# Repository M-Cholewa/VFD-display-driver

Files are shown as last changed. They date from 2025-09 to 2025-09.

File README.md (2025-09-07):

# VFD Display Driver – HL-D336WA

This project provides both hardware (PCB) and firmware (FreeRTOS-based) for driving a **cheap HL-D336WA VFD display** (around $3 from China).  
The PCB was manufactured by **JLCPCB**, and the driver allows the display to be controlled through **SPI**.

Check out the **[Reddit r/electronics discussion here](https://www.reddit.com/r/electronics/comments/1n96cpo/my_3_vfd_vacuum_fluorescent_display_driver/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).**

---

**Display – All Segments Enabled**  
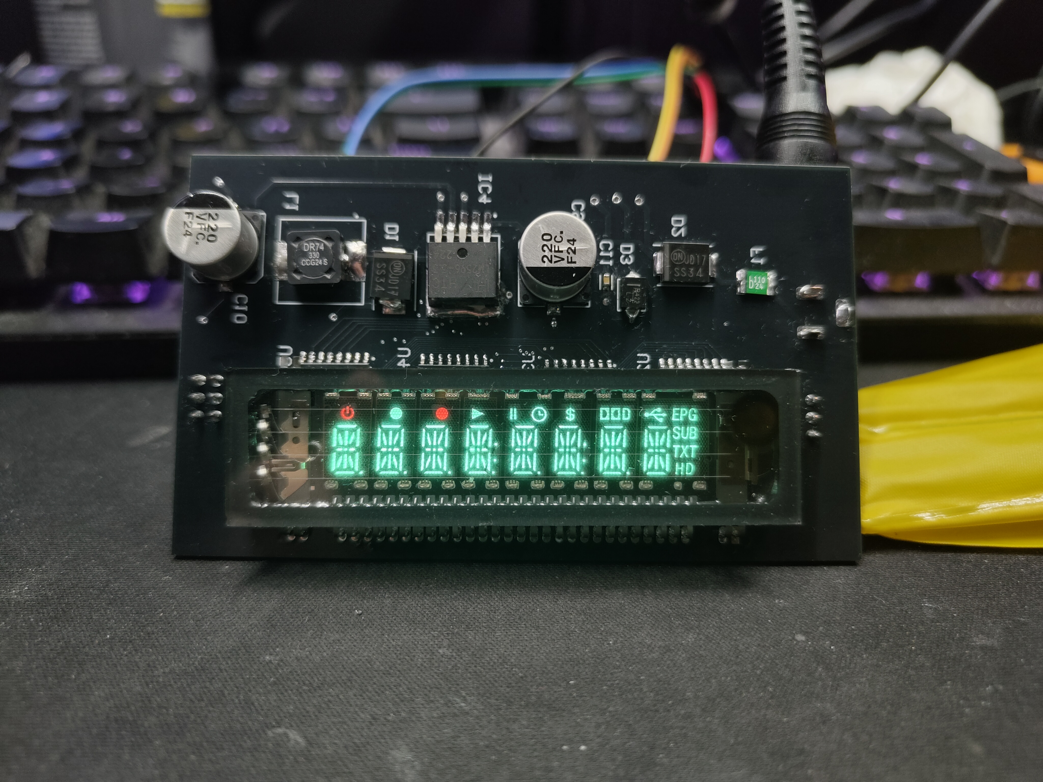
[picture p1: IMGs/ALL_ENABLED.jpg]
ALL_ENABLED


## Features

- Support for the **HL-D336WA VFD display**
- **FreeRTOS firmware** for efficient task handling
- **SPI interface** for control
- Example script for **Raspberry Pi** included ([`/RPI_SCRIPT`](./RPI_SCRIPT))
- Refresh rate: **60 Hz**
- Full control over **each segment and column**

---

## Hardware Notes

⚠️ **Important schematic note:**  
The provided schematic is **not 100% correct**.  
- Pins **COM** of the `ULN2003ADR` were incorrectly tied to **GND**.  
- To make the board work, the COM pins had to be **lifted during soldering** (left floating).  

Please keep this in mind if you want to replicate the hardware.

---

## Repository Structure

- `/FW` – FreeRTOS firmware for the controller  
- `/HW` – Hardware design files  
- `/RPI_SCRIPT` – Example Python script for Raspberry Pi to display data  
- `/IMGs` – Images, PCB renders, and schematic  

---

## Raspberry Pi Example

The controller can be driven directly via **SPI**.  
An example script is provided in [`/RPI_SCRIPT`](./RPI_SCRIPT), showing how to send data to the display.

---

## Schematic

📄 [Main schematic PDF](./IMGs/VFD_controller_stm_SCHEMATIC.pdf)

---

## Hardware Interfaces & Power

The board includes connectors for **SPI**, **SWD**, and a **DC power jack** (male, angled 90°, THT, 5.5/2.5 mm). Power is supplied from a standard **19 V laptop adapter**, which is then stepped down by an onboard converter to **3.3 V for the CPU**. The **SPI interface is galvanically isolated** using an **ADUM1401**, and the board is protected against short circuits with a **1 A PTC fuse** and **SS34 diode**.

All connectors are ESD protected.

---

## Screenshots & Diagrams

**Main Board Schematic**  
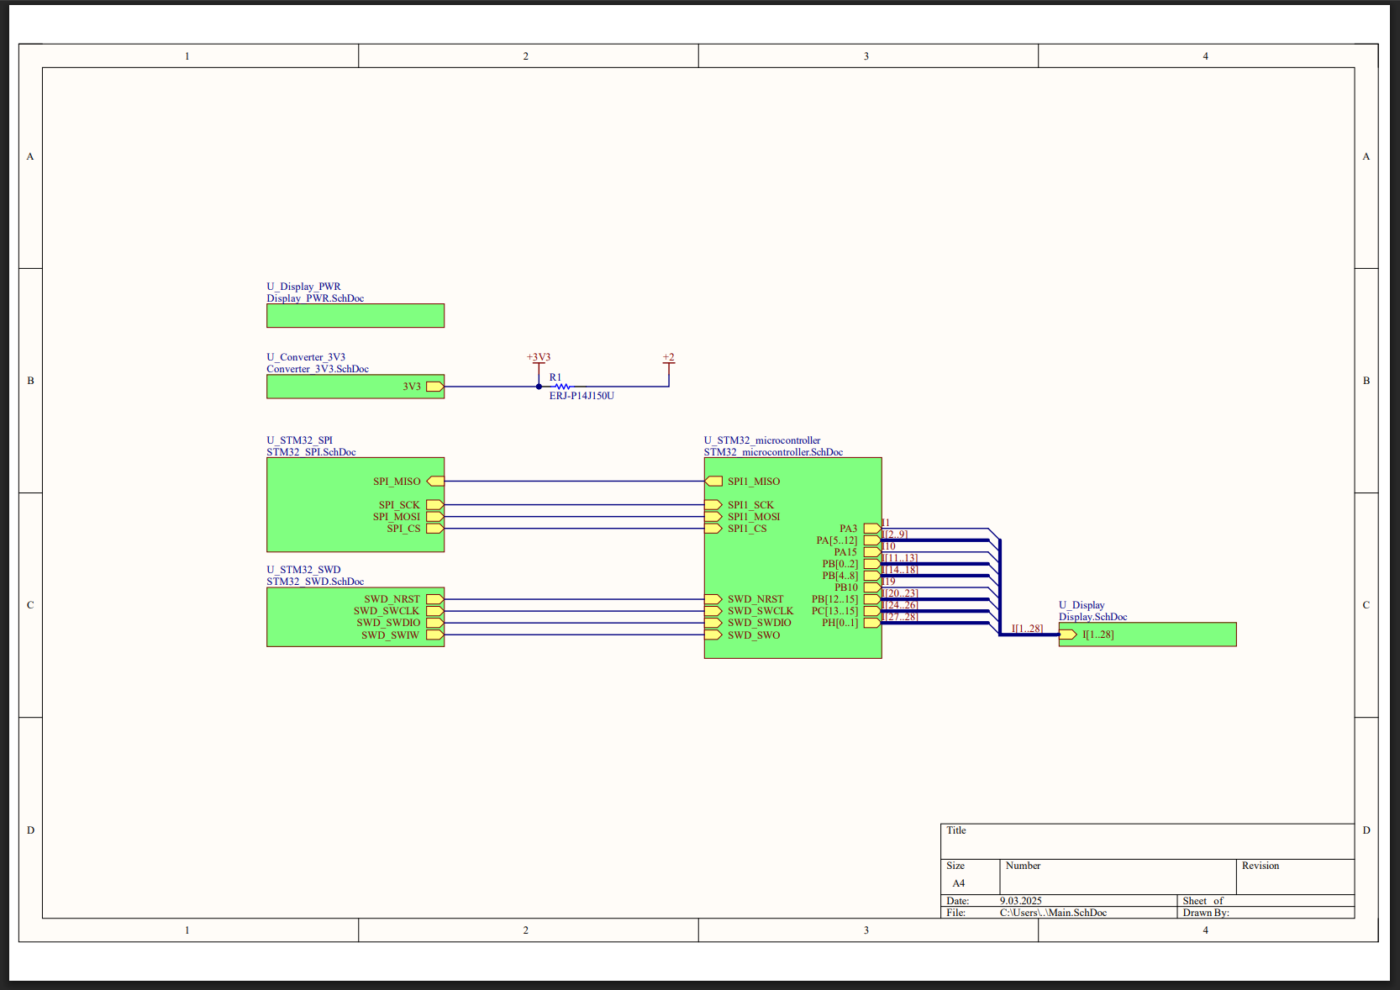
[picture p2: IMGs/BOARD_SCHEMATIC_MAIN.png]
BOARD_SCHEMATIC_MAIN


**ULN2003 VFD Driver Schematic**  
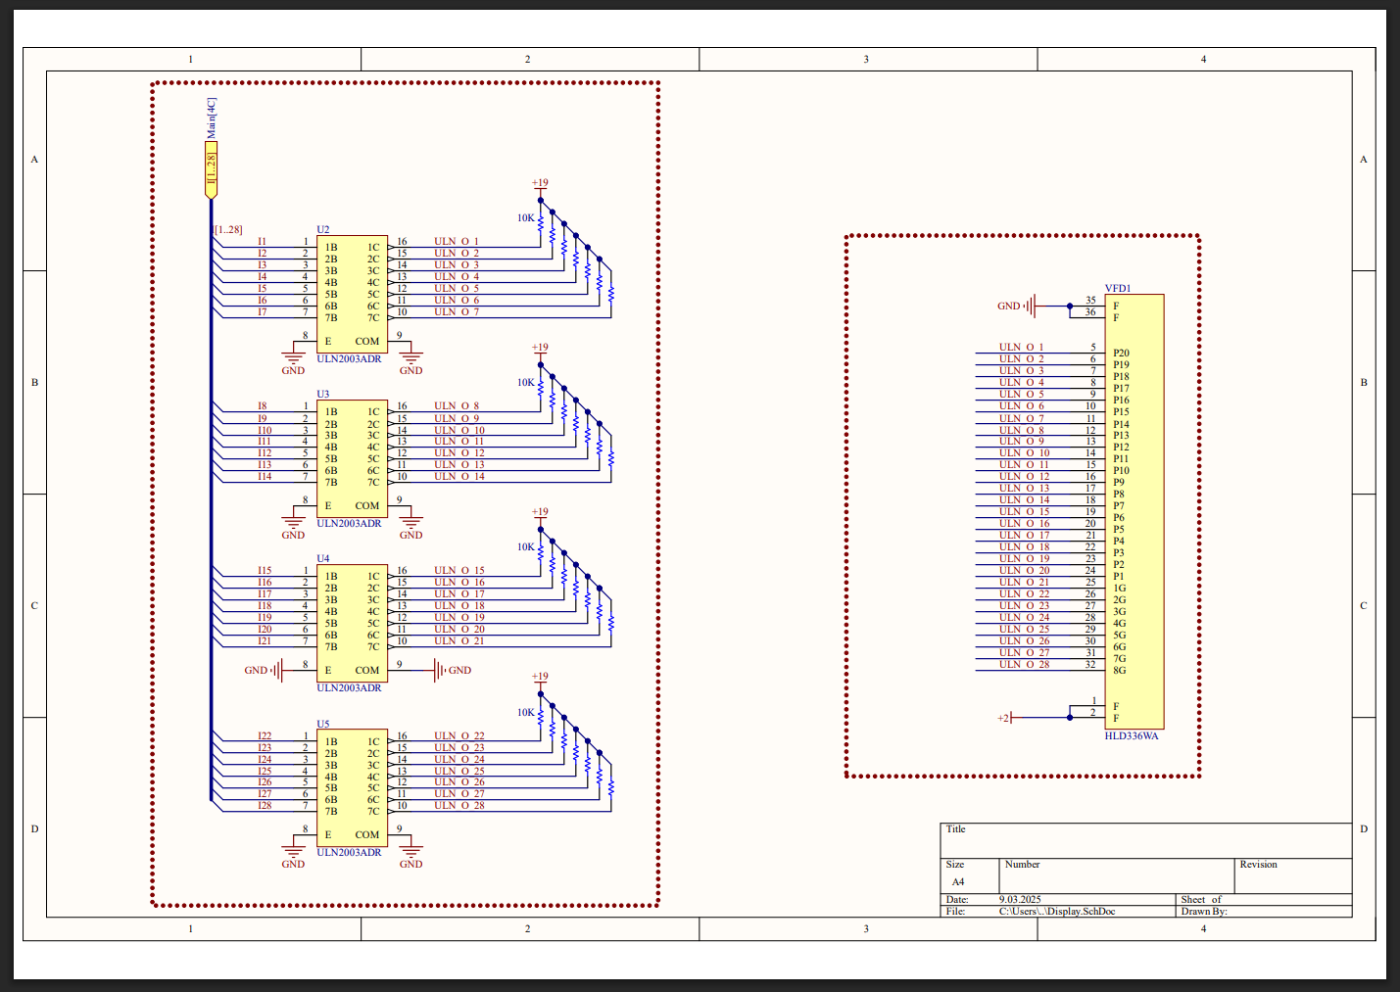
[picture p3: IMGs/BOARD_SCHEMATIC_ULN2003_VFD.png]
BOARD_SCHEMATIC_ULN2003_VFD


**PCB – Front (without display)**  
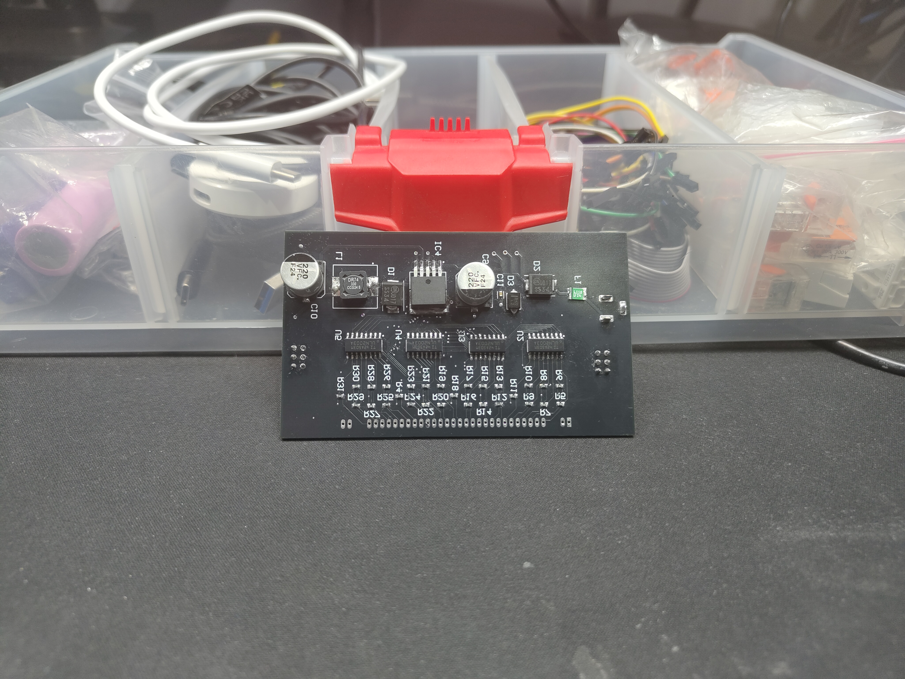
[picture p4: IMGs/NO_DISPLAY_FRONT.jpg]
NO_DISPLAY_FRONT


**PCB – Back**  
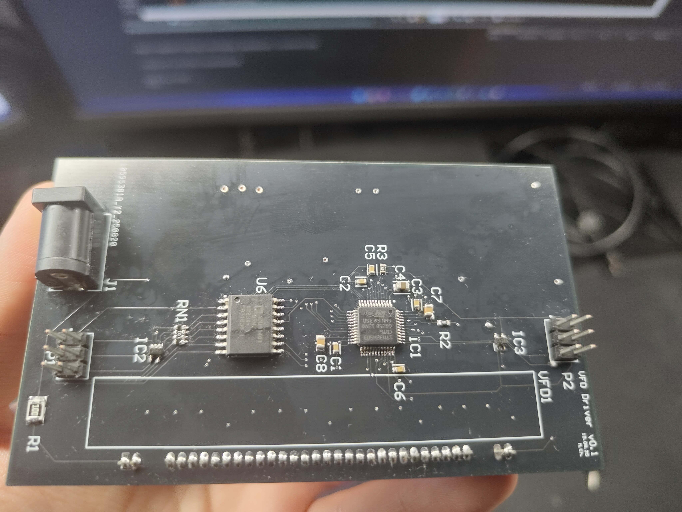
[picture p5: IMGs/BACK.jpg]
BACK


**Display – With Dark Foil**  
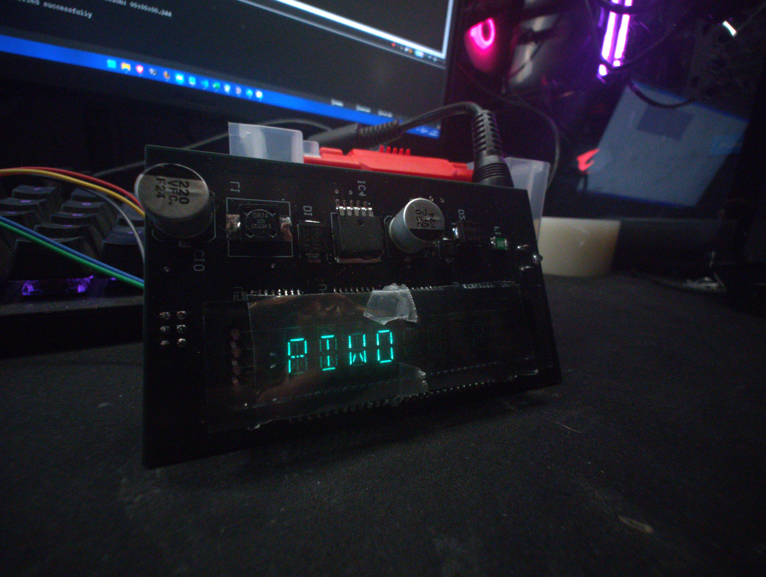
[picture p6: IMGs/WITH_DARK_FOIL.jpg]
WITH_DARK_FOIL


**Raspberry Pi Connection Example**  
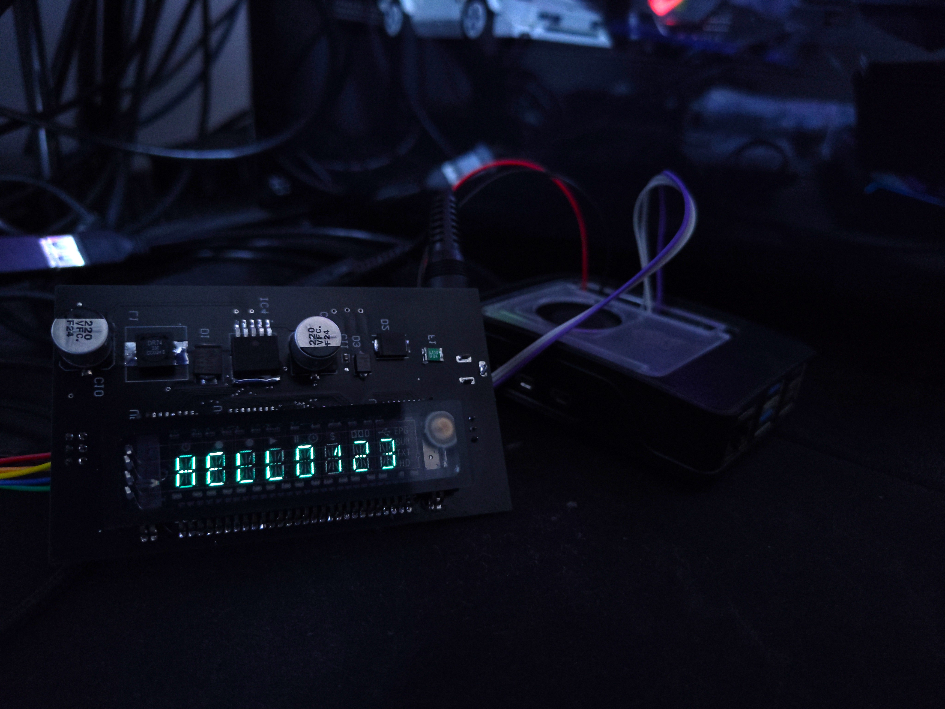
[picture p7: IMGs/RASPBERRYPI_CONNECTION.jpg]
RASPBERRYPI_CONNECTION


**Firmware Task Diagram**  
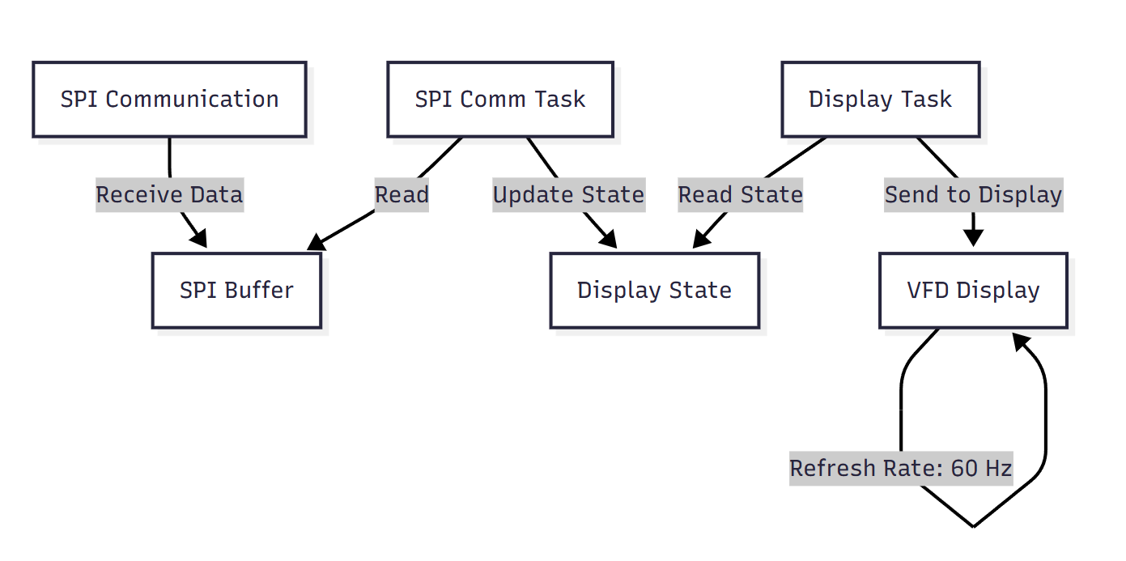
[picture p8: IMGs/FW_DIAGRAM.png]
Firmware Diagram


---

## License

MIT License – see [LICENSE](./LICENSE) for details.

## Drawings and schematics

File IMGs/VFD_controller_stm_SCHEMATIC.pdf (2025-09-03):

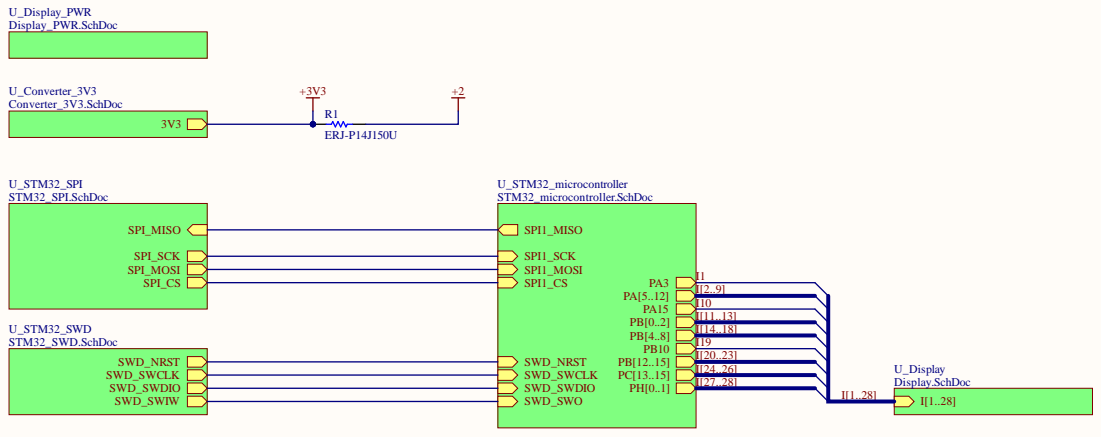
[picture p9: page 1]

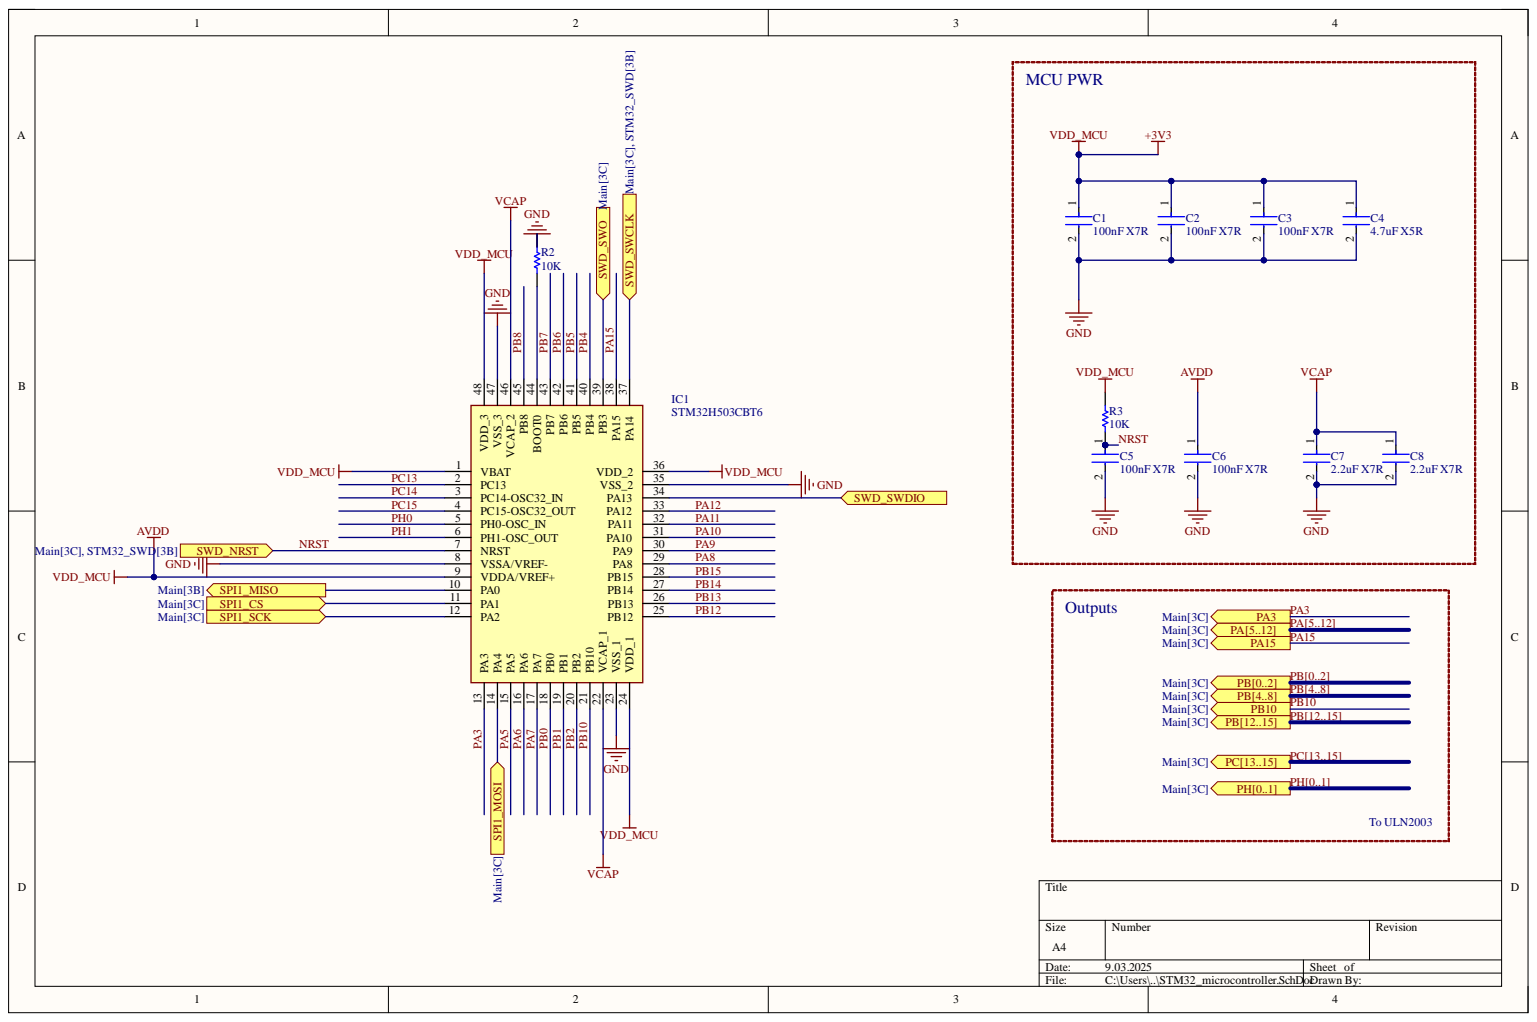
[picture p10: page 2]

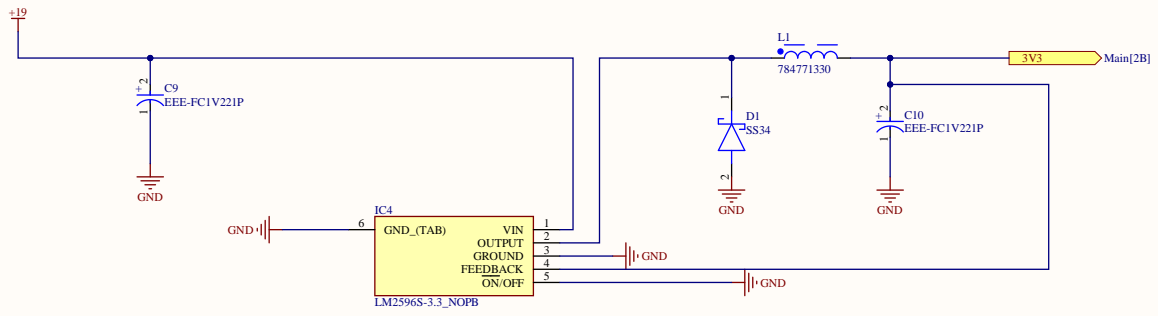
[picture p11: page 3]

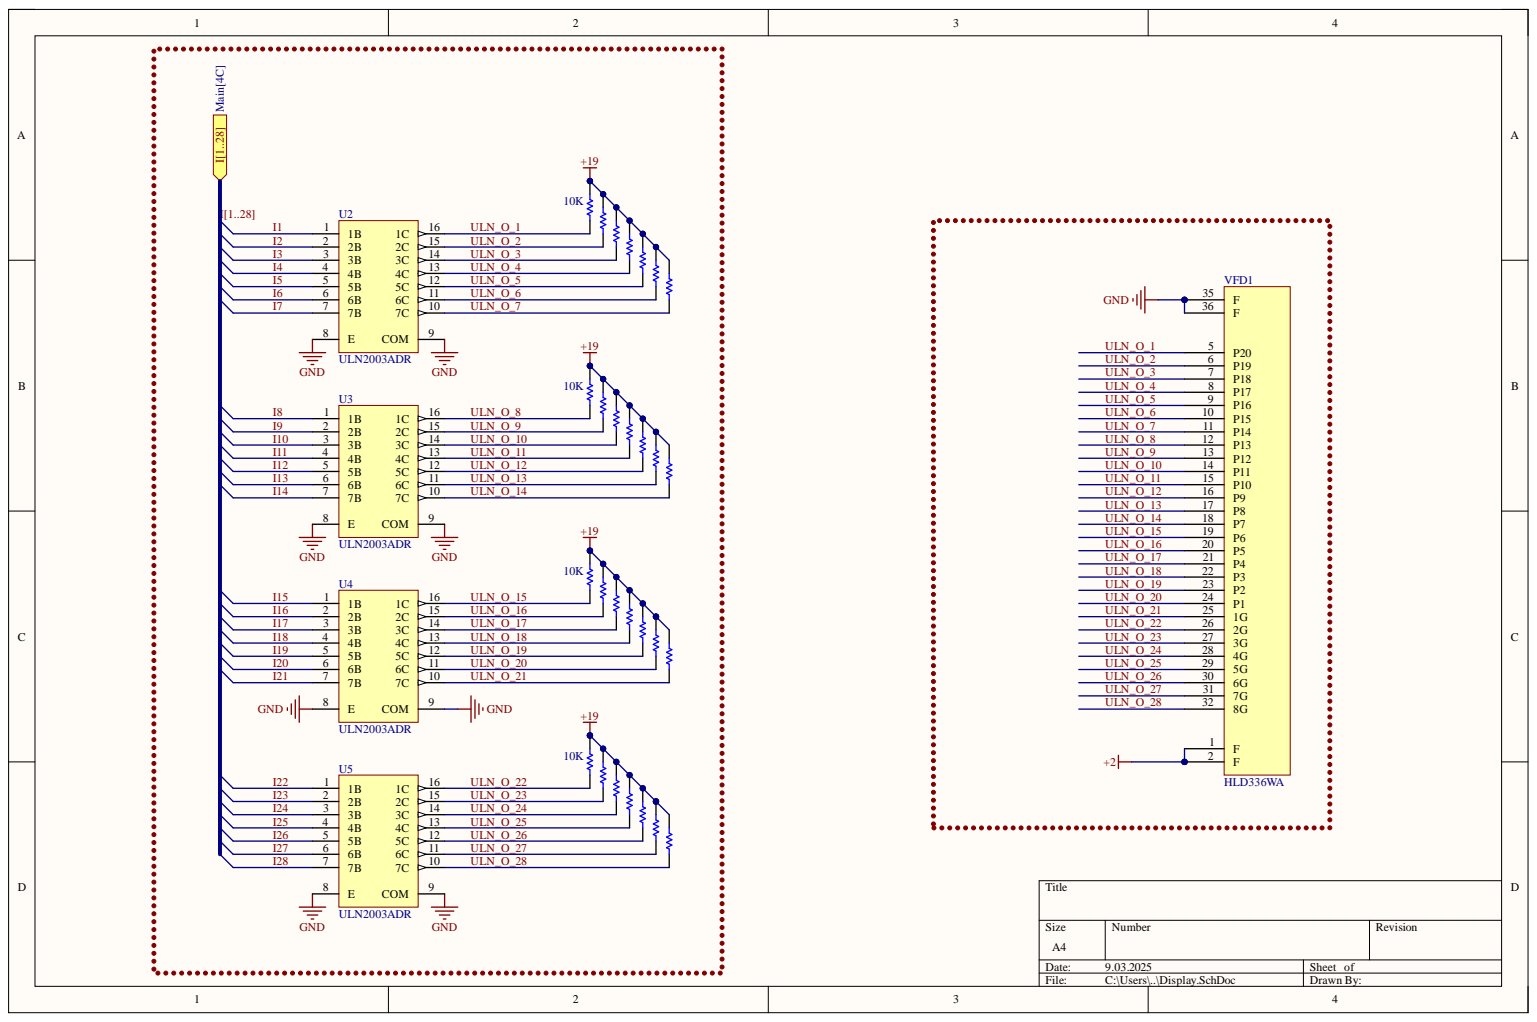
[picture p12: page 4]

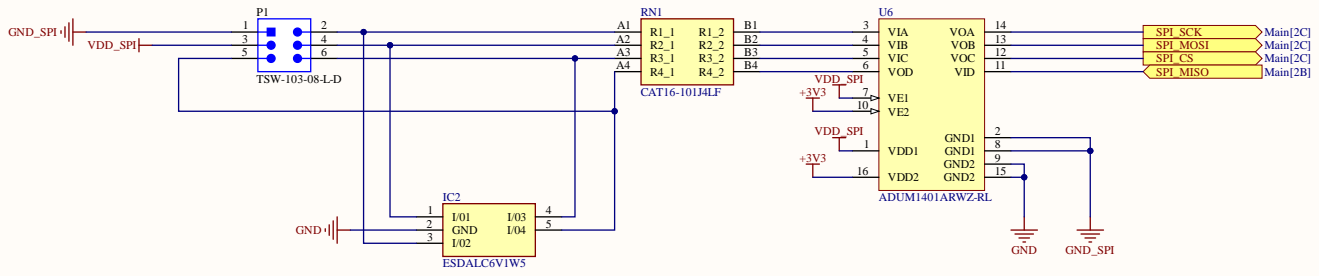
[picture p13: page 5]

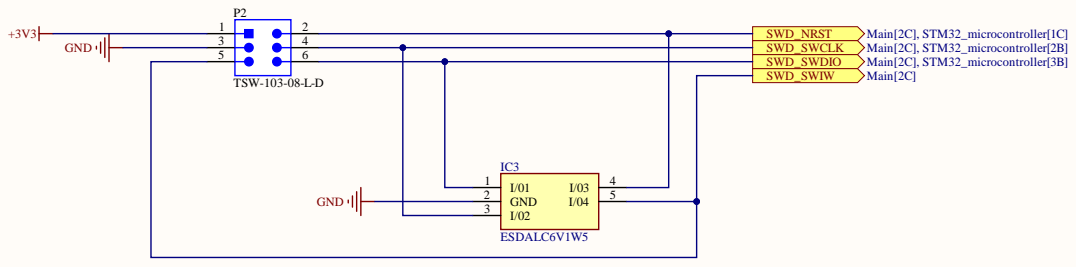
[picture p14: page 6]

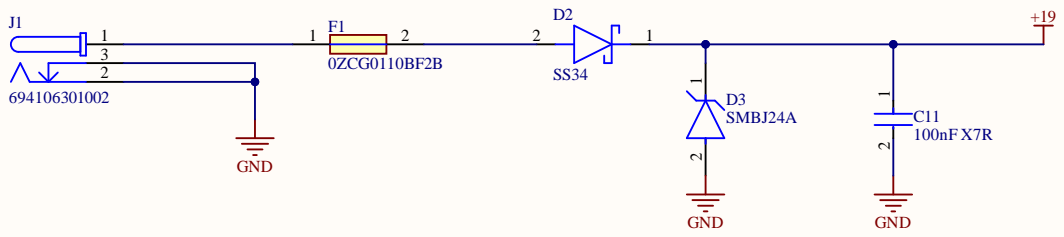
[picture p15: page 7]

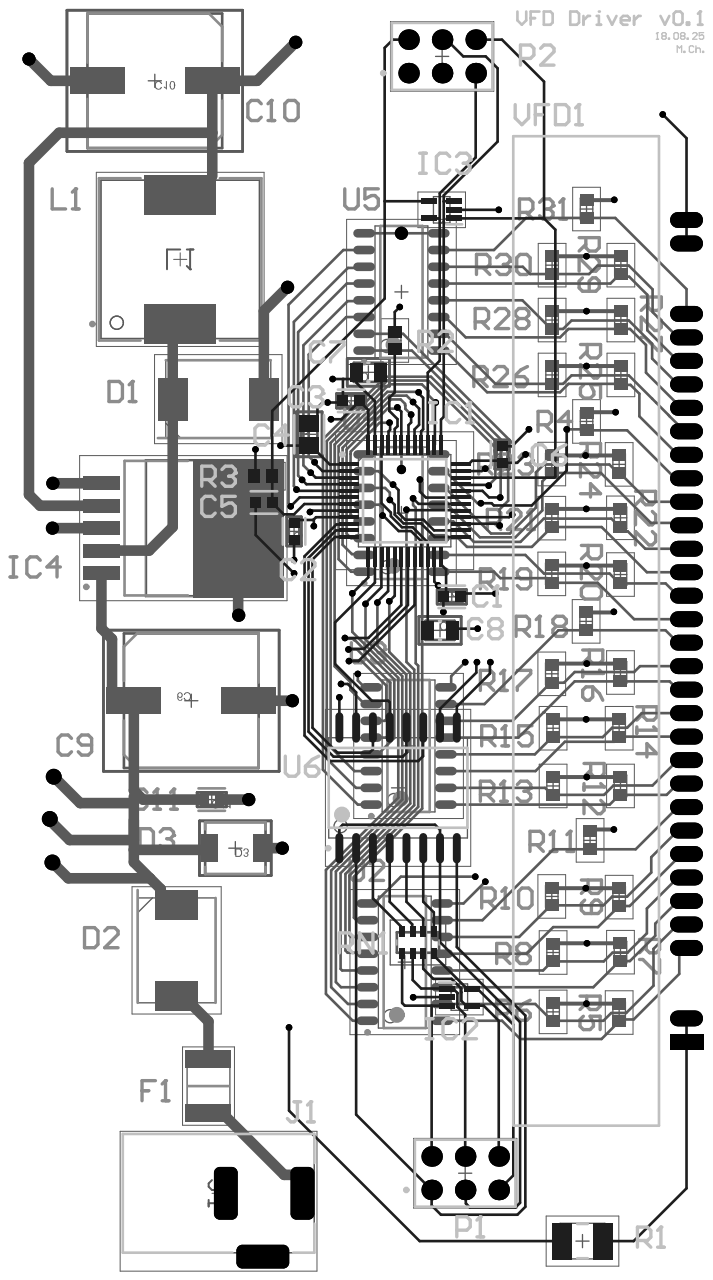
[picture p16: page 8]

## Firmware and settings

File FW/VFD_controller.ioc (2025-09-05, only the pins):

Mcu.UserName=STM32H503CBTx
PA0.Signal=SPI1_MISO
PA1.GPIO_Label=SPI1_CS
PA1.Signal=SPI1_NSS
PA10.GPIO_Label=IO7
PA10.Signal=GPIO_Output
PA11.GPIO_Label=IO8
PA11.Signal=GPIO_Output
PA12.GPIO_Label=IO9
PA12.Signal=GPIO_Output
PA13(JTMS/SWDIO).GPIO_Label=SWD_SWDIO
PA13(JTMS/SWDIO).Signal=DEBUG_JTMS-SWDIO
PA14(JTCK/SWCLK).GPIO_Label=SWD_SWCLK
PA14(JTCK/SWCLK).Signal=DEBUG_JTCK-SWCLK
PA15(JTDI).GPIO_Label=IO10
PA15(JTDI).Signal=GPIO_Output
PA2.Signal=SPI1_SCK
PA3.GPIO_Label=IO1
PA3.Signal=GPIO_Output
PA4.Signal=SPI1_MOSI
PA5.GPIO_Label=IO2
PA5.Signal=GPIO_Output
PA6.GPIO_Label=IO3
PA6.Signal=GPIO_Output
PA7.GPIO_Label=IO4
PA7.Signal=GPIO_Output
PA8.GPIO_Label=IO5
PA8.Signal=GPIO_Output
PA9.GPIO_Label=IO6
PA9.Signal=GPIO_Output
PB0.GPIO_Label=IO11
PB0.Signal=GPIO_Output
PB1.GPIO_Label=IO12
PB1.Signal=GPIO_Output
PB10.GPIO_Label=IO19
PB10.Signal=GPIO_Output
PB12.GPIO_Label=IO20
PB12.Signal=GPIO_Output
PB13.GPIO_Label=IO21
PB13.Signal=GPIO_Output
PB14.GPIO_Label=IO22
PB14.Signal=GPIO_Output
PB15.GPIO_Label=IO23
PB15.Signal=GPIO_Output
PB2.GPIO_Label=IO13
PB2.Signal=GPIO_Output
PB3(JTDO/TRACESWO).GPIO_Label=SWD_SWO
PB3(JTDO/TRACESWO).Signal=DEBUG_JTDO-SWO
PB4(NJTRST).GPIO_Label=IO14
PB4(NJTRST).Signal=GPIO_Output
PB5.GPIO_Label=IO15
PB5.Signal=GPIO_Output
PB6.GPIO_Label=IO16
PB6.Signal=GPIO_Output
PB7.GPIO_Label=IO17
PB7.Signal=GPIO_Output
PB8.GPIO_Label=IO18
PB8.Signal=GPIO_Output
PC13.GPIO_Label=IO24
PC13.Signal=GPIO_Output
PC14-OSC32_IN(OSC32_IN).GPIO_Label=IO25
PC14-OSC32_IN(OSC32_IN).Signal=GPIO_Output
PC15-OSC32_OUT(OSC32_OUT).GPIO_Label=IO26
PC15-OSC32_OUT(OSC32_OUT).Signal=GPIO_Output
PH0-OSC_IN(PH0).GPIO_Label=IO27
PH0-OSC_IN(PH0).Signal=GPIO_Output
PH1-OSC_OUT(PH1).GPIO_Label=IO28
PH1-OSC_OUT(PH1).Signal=GPIO_Output

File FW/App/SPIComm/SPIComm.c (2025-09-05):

/*
 * SPIComm.c
 *
 *  Created on: Sep 4, 2025
 *      Author: Mateusz
 */

/********************** NOTES *************************************************
 ...
 *******************************************************************************/
/* Includes ------------------------------------------------------------------*/
#include "SPIComm.h"
#include "HLD336WA_State.h"

//<<<<<<<<<<<<<<<<<<<<<<<<<<<<<<<<<<<<<<<<<<<
//#ifdef USERLIB_USE_ENABLED // plik.c
//>>>>>>>>>>>>>>>>>>>>>>>>>>>>>>>>>>>>>>>>>>>
/* Private define ------------------------------------------------------------*/

/* Private macros ------------------------------------------------------------*/

/* Private typedef -----------------------------------------------------------*/

/* Private constants ---------------------------------------------------------*/

/* Private variables ---------------------------------------------------------*/
extern const SPIComm_ll_drv_t SPIComm_ll_drv_stm;
/* Private function declaration ----------------------------------------------*/

/* Public functions definition -----------------------------------------------*/

ErrorStatus SPIComm_Init(void)
{
	return SPIComm_ll_drv_stm.Init( NULL );
}

uint32_t SPIComm_GetAnodes(uint8_t grid)
{
	if ( grid > 7 )
	{
		return 0;
	}

	return SPIComm_ll_drv_stm.GetAnodes( grid );
}

ErrorStatus SPIComm_ProcessingTask(void)
{
	for ( uint8_t i = 0; i < 8; i++ )
	{
		uint32_t val = SPIComm_GetAnodes( i );
		HLD336WA_State_SetAnodes( i, val );
	}

	return SUCCESS;
}

/* Private functions definition ----------------------------------------------*/

//<<<<<<<<<<<<<<<<<<<<<<<<<<<<<<<<<<<<<<<<<<<
//#endif /* USERLIB_USE_ENABLED */ // plik.c
//>>>>>>>>>>>>>>>>>>>>>>>>>>>>>>>>>>>>>>>>>>>

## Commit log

2025-09-03 HW and FW added.
    Added .gitignores.
    No readme and imgs yet.
    [Converter_3V3.SchDoc, Display.SchDoc, Display_PWR.SchDoc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]
2025-09-05 Added SPI communication Added Python script for RPI5 to communicate through SPI
